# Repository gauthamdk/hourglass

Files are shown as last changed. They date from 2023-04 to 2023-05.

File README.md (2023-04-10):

# hourglass

### [Ideation + Laser Cut Experiment | April 6, 2023 ](https://github.com/gauthamdk/hourglass/tree/main/ideation)

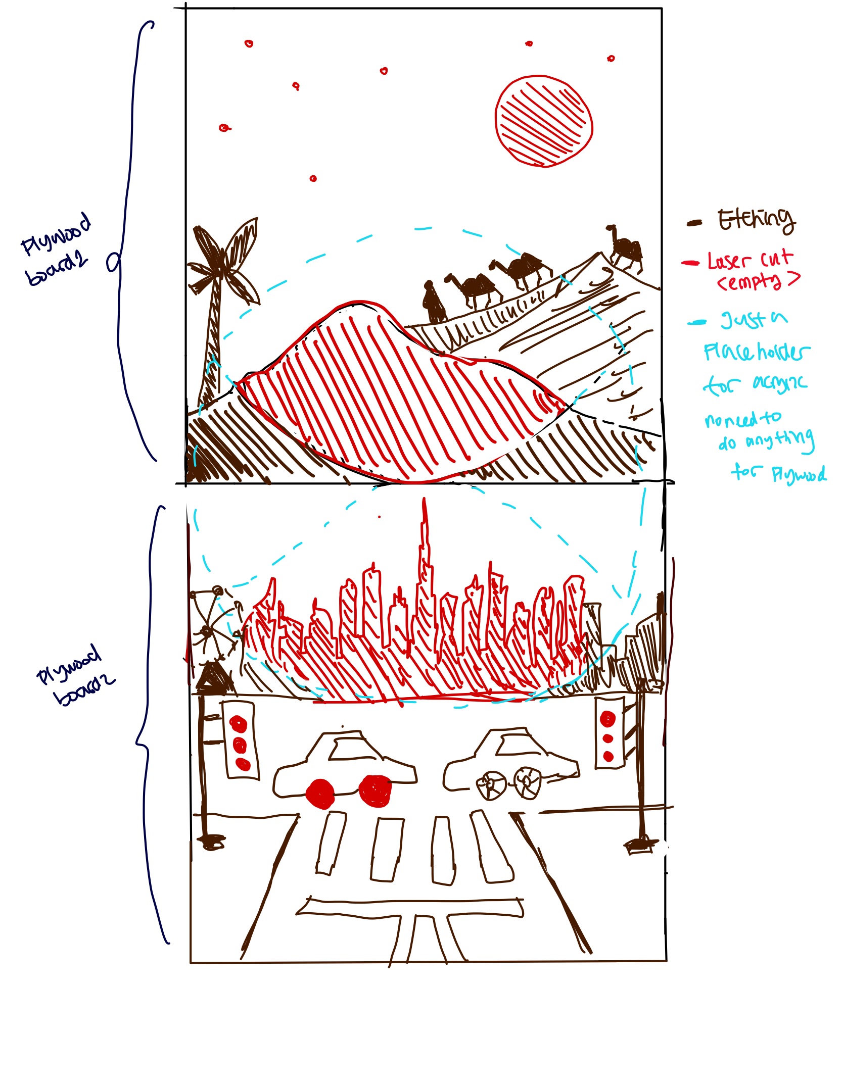
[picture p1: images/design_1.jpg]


# Core Idea
The core concept of our project is to illustrate the flow of time in the U.A.E. using the flow of sand. The project will occupy two boxes, 100cm long and 50cm wide, vertically oriented. A flat hourglass will be placed between the two boxes at the center of the piece, and will rotate at the beginning of every hour. The placement of the hourglass will be exactly at the center of the piece, 25cm below the top and 25cm above the bottom. Another layer of lasercutted acrylic will conceal the hour glass from viewers, only showing certain parts of the flowing sand. The contents of the acrylic board is detailed below. 

# Design Details
The flow of time will be portrayed through the artistic cutouts of the acrylic board, covering the entire span of the two wooden boxes. The design of the top half of the board will portary the U.A.E. of the past, and the bottom half will show the U.A.E. today. If the piece is split into four sections from top to bottom, the flow of sand will be shown in the 2/4 and 3/4 section, and the 1/4 and 4/4 sections will be decorational and supplemental. 

## The 1/4 Section
In this section, we will have cutouts of stars and the Sun on the acrylic board. White light will be placed behind the stars, and an orange/red light will be placed behind the Sun. When the 2/4 section (old U.A.E.) is full of sand, the Sun's light will be on full brightness, and the stars' lights will be the most dim. As sand flows from the 2/4 section to the 3/4 section (new U.A.E.), the Sun's light will progressively get dimmer and the stars' lights brighter. When 2/4 has no sand left, the stars will be on full brightness and the Sun will have no light. 

The goal of section 1/4 is to demonstrate old U.A.E. fading with time, with the Sun metaphorically setting as night time comes. 

## The 2/4 Section
This section will portray sand dunes, camels, and the inhabitants of the U.A.E. decades ago. In the fan shaped window where the sand from the hourglass is visible, the acrylic board will be fully hollow. For example, the sand dunes will be hollow, allowing the actual sand from the hourglass to providing the fillings of the cutouts. The sections of 2/4 that does not have the hourglass behind it will still continue the image of the sand dune, but will be laser etched instead of cut. These are the places that the camels and inhabitants will be placed. 

## The 3/4 Section
This section will portray the new U.A.E., mirroring section 2/4 in terms of its layout. The parts that have the hourglass behind it will be hollow, portraying iconic buildings of the U.A.E such as the grand mosque and the Burj Khalifa. The parts that do not have the hourglass behind will be etched instead, displaying Etihad and Emirates airplanes. 

## The 4/4 Section
This section will be complimentary to section 3/4, with cars and street lights etched and cut into the board. The body of the cars will likely be cut, and the wheels of the cars will be hollow, with actual mini-wheels protruding from the surface. The body of the street lights will be etched, with the actual light bulbs hollow. LED lights will be placed behind these light bulbs. As sand flows from section 2/4 to 3/4, the wheels of the cars will go from static to fully spinning, and the street lights will go from dim to full brightness.

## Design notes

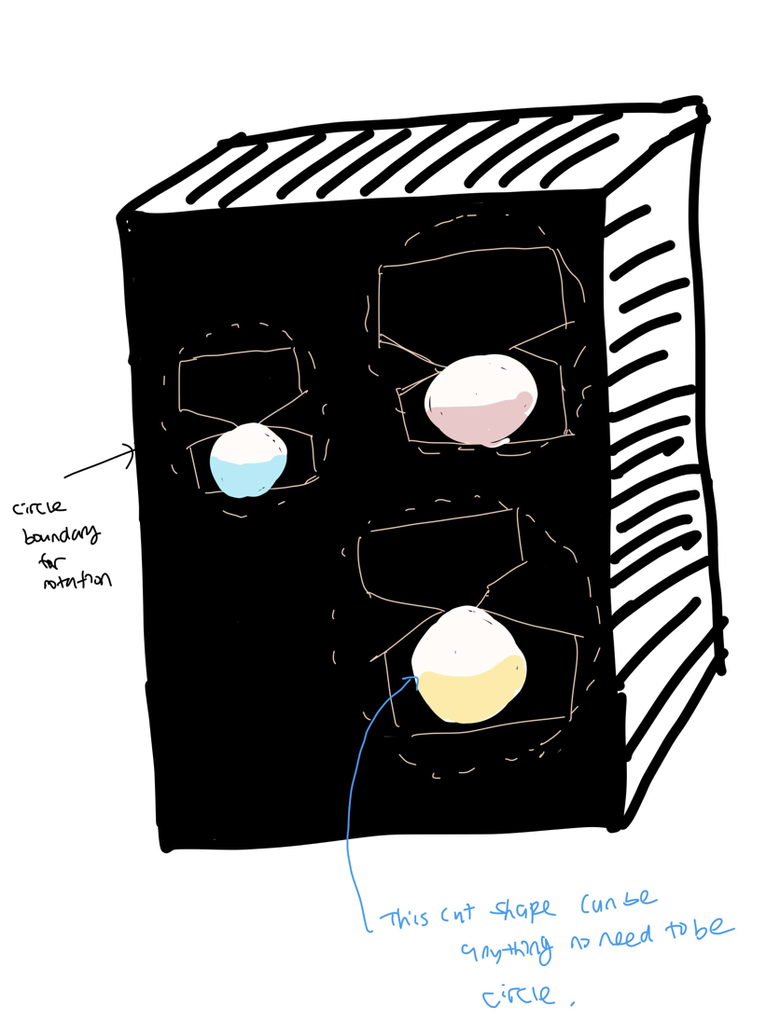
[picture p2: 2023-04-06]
images/rotation_mechanics.png

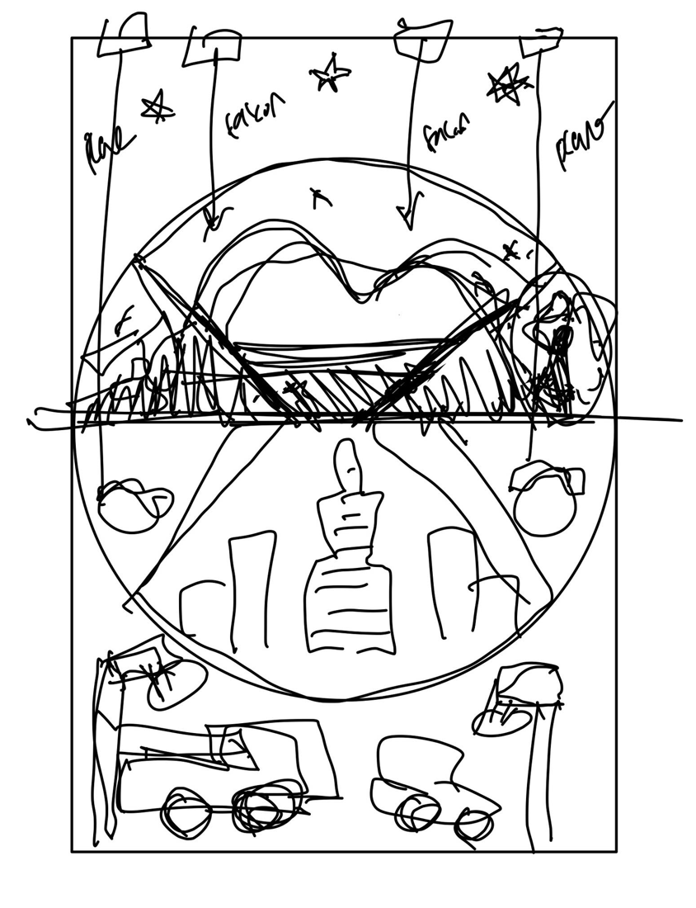
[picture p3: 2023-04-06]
images/oldtonew.1.png

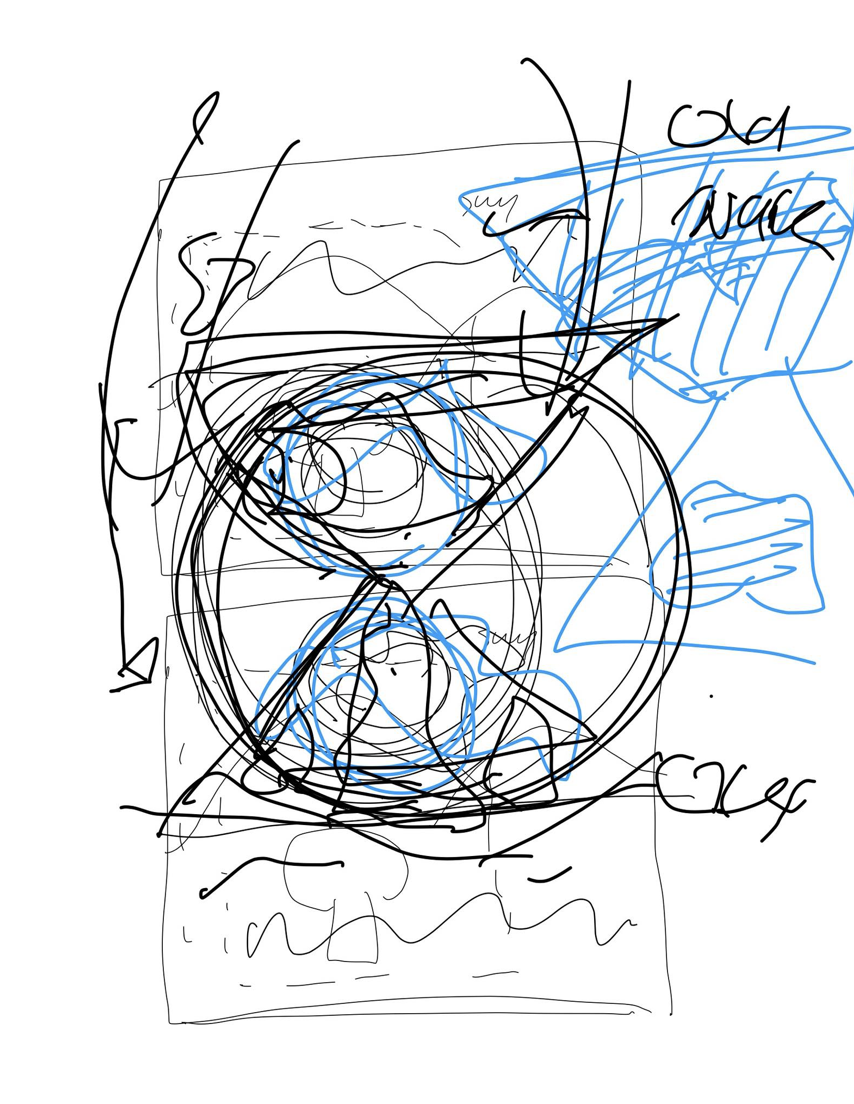
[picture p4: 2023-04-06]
images/rotation.png

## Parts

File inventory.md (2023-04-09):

# Items List

1. 50 x 50 cm acrylic board for hourglass (laser cut hourglass shape)
2. 50 x 50 cm (2 pieces) for sandwiching the hourglass plywood
3. 2 boxes from Professor Shiloh to form 2 storeys
4. 100 x 50 cm plywood for laser cutting shapes for dunes, stars and buildings and etching for cars, falcons, etc.
5. Servo motor to spin the hourglass
6. Fine sand to fill the hourglass. 
7. LED lights for stars

## Items if time permits

1. Servos to move falcon wings
2. DC motor to move car tires
3. 3D printing or laser cutting the falcons

# TODO

1. Prototype hourglass with cardboard
2. Draw hourglass shape on illustrator
3. Draw scene with cutout and etching on illustrator
4. Prototype the scene with cardboard
5. Adjust based on prototypes
6. Build final pieces with plywood and acrylic
7. Build platform to place servo 
8. Get sand for hourglass

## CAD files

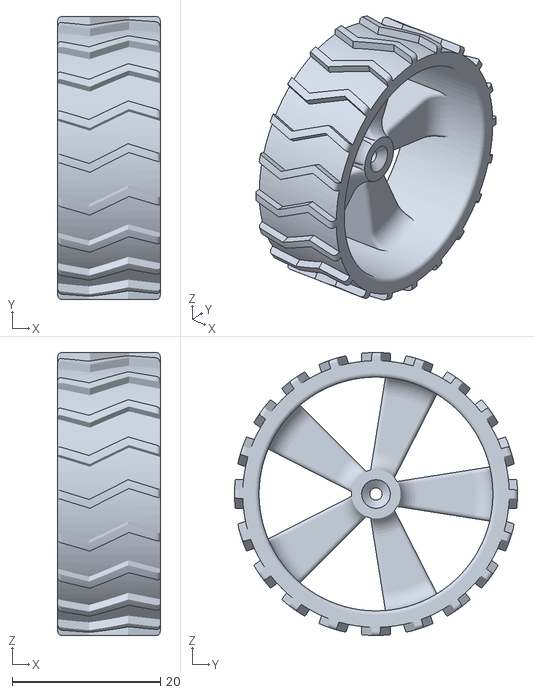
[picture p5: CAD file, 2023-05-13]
Wheel(1).stl
13.8 x 38.2 x 38.2

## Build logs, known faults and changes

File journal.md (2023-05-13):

# April 10th
In this class session, we divided our work into hourglass prototyping and illustrator designing. Nathan mainly worked on the hourglass prototype, and Gautham and Soojin were designing the acrylic cutouts. 

## Hourglass prototype
Due to a lack of acrylic material, we decided to use cardboard to simulate an acrylic hourglass. In the previous class, we had breifly lasercut a cardboard hourglass, and that was the hourglass we worked with in this prototype. The main difference between cardboard and acrylic for our project was that we had to address the holes on the side of the cardboards, which we simly taped up. Here is the cardboard hourglass:

<p align="center" width="100%">
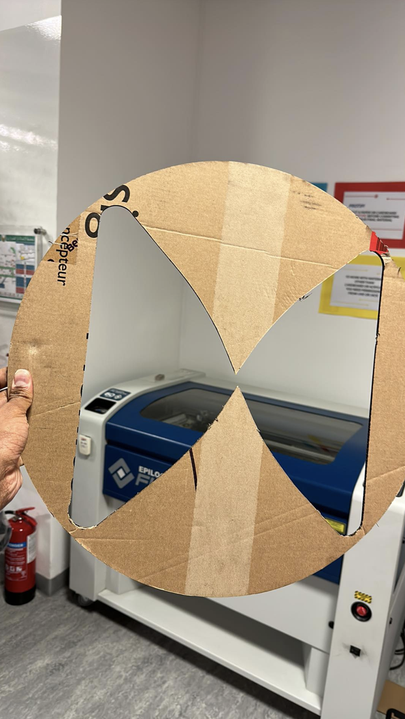
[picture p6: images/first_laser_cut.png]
    
</p>

Next, we glued the cardboard hourglass to a flat cardboard surface, and then started filling in the hourglass with sand. Since we want the sand from the hourglass to provide a solid filling for the plywood cutout in the front, the sand needed to perfectly fill in half of the hourglass. After some trial and error, the sand filling was completed, and we moved onto gluing a transparent acrylic board onto the sand-filled hourglass. This proved to be the hardest part of the prototype, as the acrylic board was heavy and hard to glue seamlessly onto the uneven cardboard surface. We tried glue guns, white glue, and acrylic glue, but none of the options worked. In the end, since the hourglass was only a prototype to test the flow rate, we decided to just use clamps to hold down all sides of the acrylic board. The prototype looked like this:

<p align="center" width="100%">
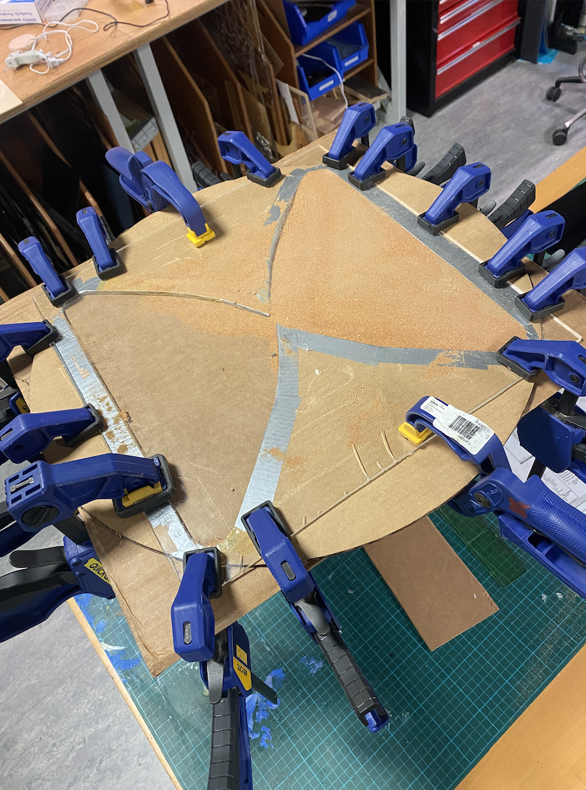
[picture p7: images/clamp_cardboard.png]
    
</p>

Even with using as many clamps as we did, the sand was still leaking from the sides, as well as going around the hourglass as it flowed down into the bottom. However, most of the sand flowed decently through the hole of the hourglass, and we were able to find out that a 5mm hole is much too big. The total flow time did not even last five seconds. Overall, this prototyping session was very helpful for us in getting a rough estimate of the hourglass dimensions. Here are some videos of the prototype: 

[Test 1](images/sand_cardboard_porrotype.MOV)
[Test 2](images/sand_cardboard_2.MOV)
[Test 3](images/sand_cardboard_3.MOV)

# April 12th
Gautham and Soojin finalized their illustrator work from April 10th, and plan to lasercut their design on April 13th. Here is the current design:
<p align="center" width="100%">
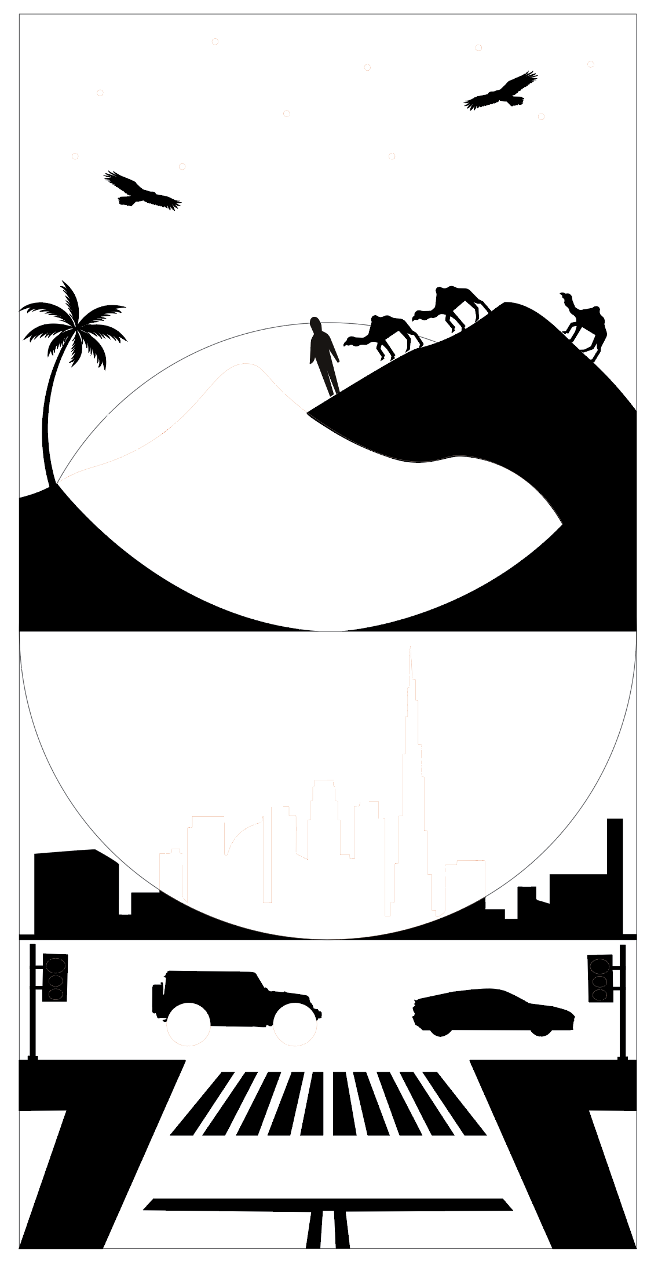
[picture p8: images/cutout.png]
    
</p>
The black circle in the middle is the area where the hourglass will rotate. The thick black strokes are all areas that will be laser etched into the plywood surface, and the think pink lines will be the places where the plywood is laser cut. There are three sections of these laser cuts, including the sand dune at the top, the U.A.E. skyline, and the wheels of the jeep underneath the skyline. 

# April 17th
During this class, we focused on prototyping and testing our laser cutting design.

## Prototyping
### Motor
Nathan and Soojin worked primarily on the prototyping process. Soojin focused on testing the hourglass, while Nathan worked on testing the motor. For the motor testing, our primary concern was the capability of the servo motor in handling the weight of the piece. We used a piece of plywood that was similar in weight to the final hourglass, bolted the servo motor onto the wood, and tested its turning ability. Despite Nathan eyeballing its centering on the wood, we found no concerns regarding the motor's capabilities for the final piece.

It's important to note that we originally designed a structure that would secure the motor to the hourglass. However, after realizing that the motor had its own securing mechanisms, we no longer believe that we need any additional mechanisms to secure the motor to the hourglass. Please see the photos and videos of the motor prototyping process below.
<p align="left" width="100%">
    
    
    
</p>
MOTOR PICS AND VIDS

### Hourglass
Soojin led the hourglass testing. For hourglass testing, our aim was to understand the behavior of sand moving from one side to the other on a thin, ribbon-shaped surface in our design. Based on the speed of the sand movement, our next step is to identify the size of the hole that connects the two sections.

For the prototype, we used acrylic as the cover, cardboard as the hourglass-shaped cutout, and another cardboard as the supporting board. The cardboards were sealed with duct tape to prevent sand from entering the corrugated space. We then clamped the three layers together to ensure enough pressure and a tight seal. Since the materials used were not consistent, such as three acrylic layers or three cardboard layers, it was difficult to "glue" them, which is why we used clamps for the experiment.

<p align="center" width="100%">

</p>

<b>Video of sand moving below:</b>
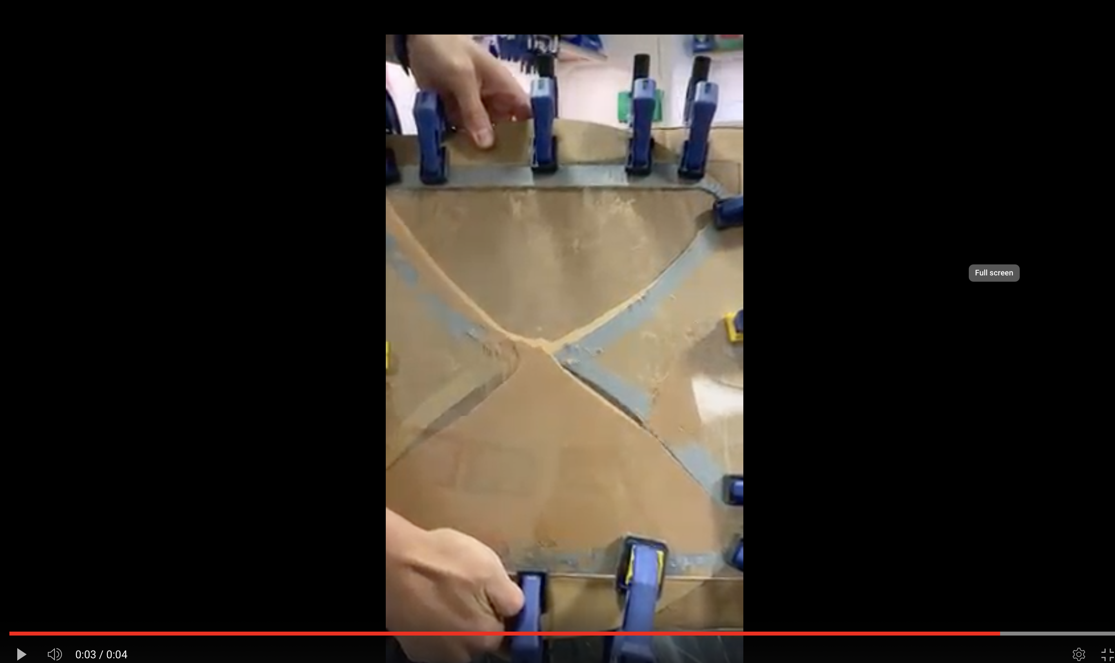
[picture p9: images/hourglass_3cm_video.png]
Image ALT text


As expected, the sand moved quickly through the hole, taking only 4 seconds to move from one side to the other. However, to achieve the desired speed of 15-20 minutes for sand to move from one place to another, we decided to try using 0.05cm for the next prototype.

[Things to consider]

- Color of sand (considering the plywood background, what color sand would be impactful?)
- Which material to use to glue acrylic to plywood
- Thickness of Acrylic
- Make hole size adjustable using nuts and bolts

## Laser Cutting
Gautham led the laser cut design testing process. The cardboard result looked great, but the laser cutting machine in the IM lab was not large enough for the full scale of our project. Therefore, we scaled down the design just to test it out. Here is how it turned out:
<p align="left" width="100%">
    
    
</p>
The initial result had some errors, such as the sand dune not being cut out and the skyline on the bottom being proportionally smaller than the sand dunes. To fix these issues, we decided to make the skyline bigger in our next design and change the skyline from Dubai to Abu Dhabi, where the building heights are more even. Additionally, we were not happy with the star design, so we changed them to actual star shapes in the second design. Please see the second design below.

# April 24th

<p align="center" width="100%">
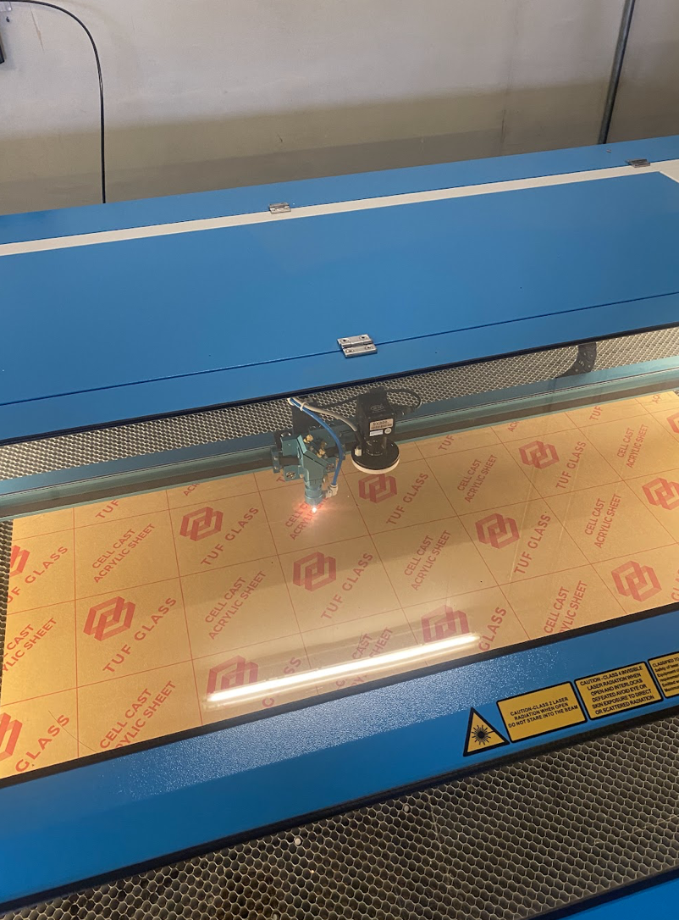
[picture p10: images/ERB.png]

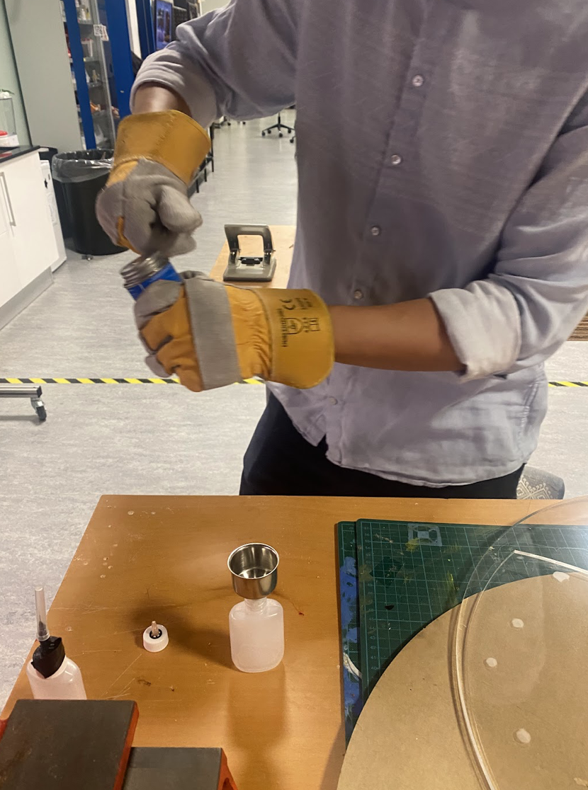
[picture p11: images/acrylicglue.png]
    
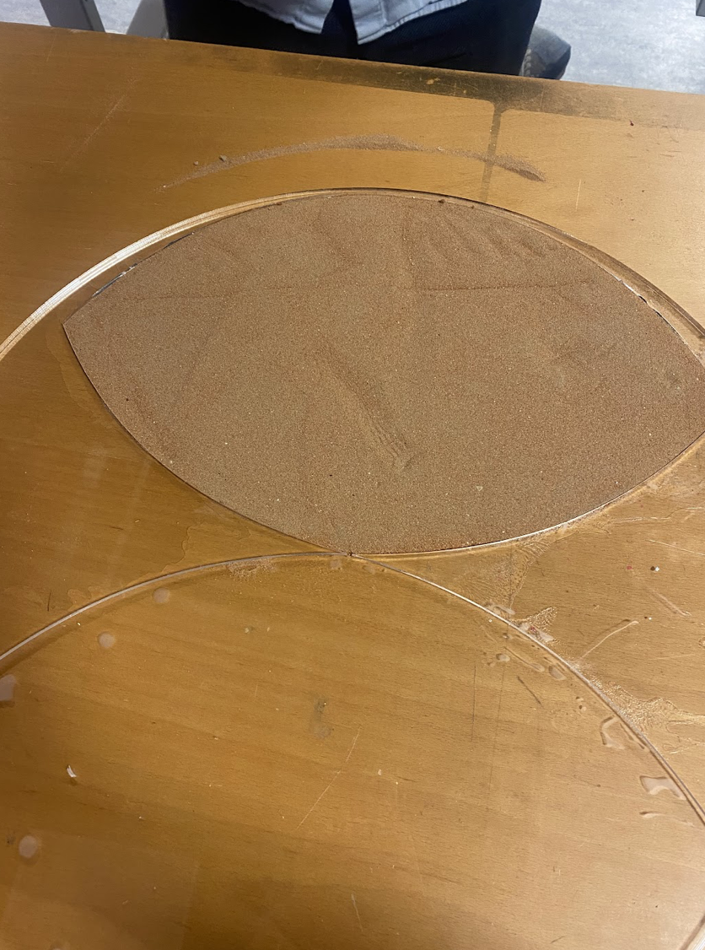
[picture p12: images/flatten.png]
    
</p>
In this class, we primrily tested out our hourglass design with actual transparent acrylic. We went to the machine lab and cut out the design with the large laser cutter, then used acrylic glue to merge the layers of the hourglass. The main issue in this step is that there are three layers of the hourglass, which makes the last layer very hard to glue. We have to trace the hourglass ledges with the glue, then blindly place the final layer on top. We did not succeed in gluing the last layer until the next day. Here is the end result:

<p align="center" width="100%">

</p>

There were a few isues. One, the last layer was not completely sealed to the rest due to the difficulty in gluing. For the final design, we will put more glue. There was also any issue of the sand getting blocked due to small rocks sealing the hourglass gap. We will sort through the batch of sand we use for the final design. Finally, the sand did not fully flow through, mainly becuase the bottom ledge of each half are curved. Small amounts of sand were tracked in the two pockets and would not flow freely. To remedy this issue, we have made the curved ledges straight. 

# April 28th
<p align="center" width="100%">
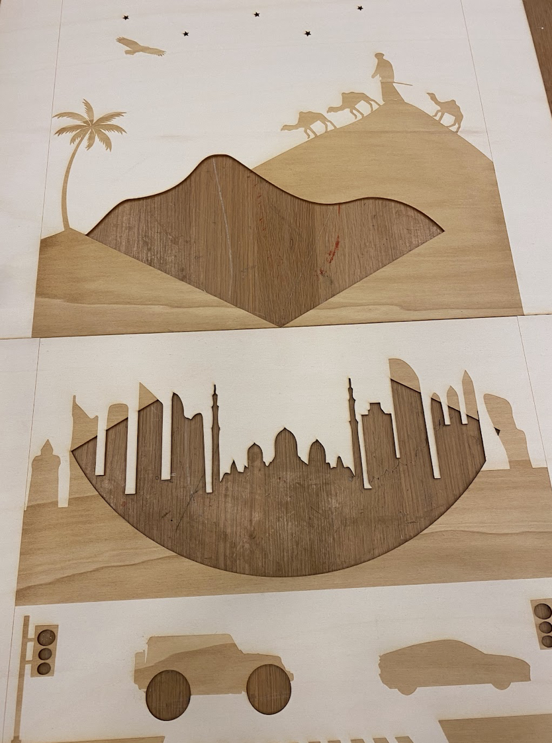
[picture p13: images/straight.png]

</p>

After encountering some trial and error with the first acrylic cut, we made a second cut. This time, we made the hole between the top and bottom of the hourglass much smaller (0.3cm) and straightened the curve to ensure that the sand flows smoothly without getting stuck. We also redesigned and laser cut the plywood board so that its line is aligned with the new straight line of the hourglass acrylic board. The acrylic board is sandwiched as such: 0.4mm thin transparent acrylic board (circle shape) 0.4mm transparent acrylic board cut to hour glass shape, and 0.8mm thick black acrylic board.

<p align="center" width="100%">
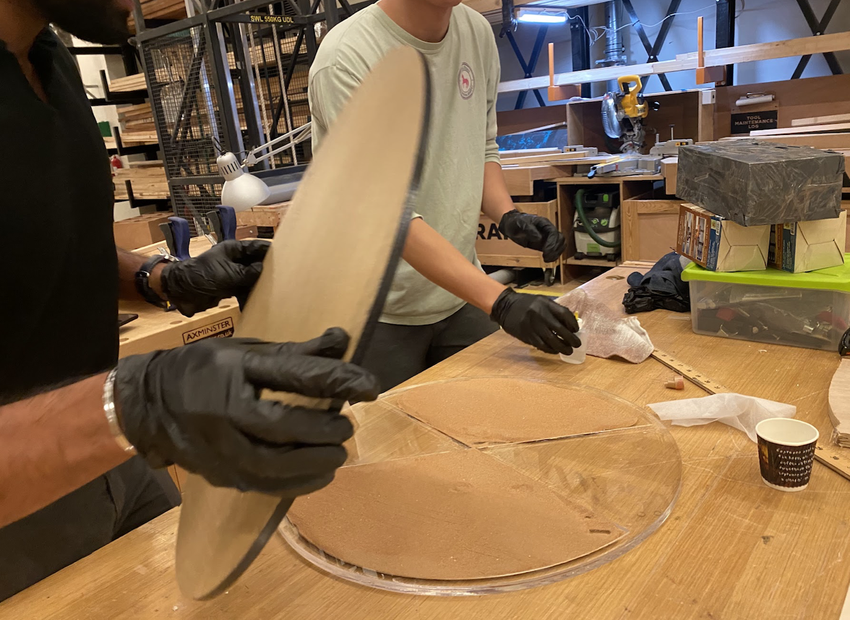
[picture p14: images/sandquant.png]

</p>

Finding the exact amount of sand to add before sealing the hourglass was difficult. Therefore, we added more than half of the sand, and then drilled a hole in the center to pour out any excess sand once the bottom is filled.

# May 1st 
We found an online model for the 3D [file](./Wheel(1).stl) of car wheels that I thought was suitable for the project. I modified the scale of the wheel to fit the cutout and sent the files to the library to print. We received it the following day and spray painted it silver to match the aesthetic.

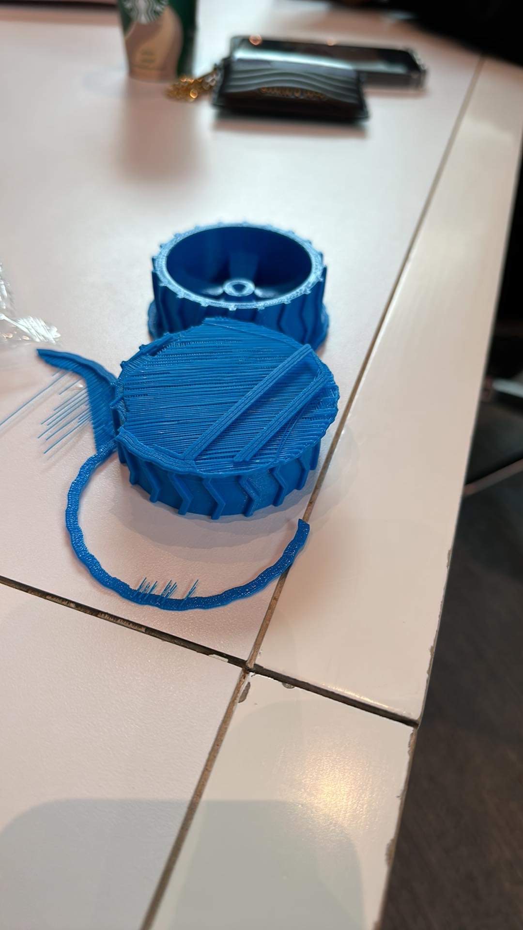
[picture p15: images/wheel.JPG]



# May 5th
We secured the frame structurally today, including implementing a floor, two supporting boards on the side, and a board in between. The "H" structure adequately secures the integrity of the frame.

We spray painted the car wheel and attached to the main plywood board. 

# May 7th 
We did some soldering for the connections on the design frame, including the soldering for the star light connections. We also drilled some holes into the board that will ultimately host all the wires and arduinos in order to provide space for the wires. 

For the light connections, I etched the stars on a smaller piece of plywood and soldered the Neopixel LEDs onto the plywood and secured them with them. We then attached this to the back of the cutout with some screws to align it properly.

# May 8th
We finalized assembling the project, including replacing all of the jumper wire connections with solder and attached the design frame to the project frame. The mechanisms did not work initially after we soldered everything, including the stars, traffic lights, and hourglass. However, after some testing with the multimeter, the professor helped us trouble shoot the issue and tidy up the connections. 

Now it was left with the code. The code was each individual component like the stars and traffic lights, the wheels and the hourglass rotation was simply to code independently. But togther I need to use millis() to count the number of minutes that passed to toggle between the different modes. 

Initially, the hourglass would rotate till sand is flowing down. As the sand flows for 3 minutes and the bottom starts getting filled, I dim the stars at the top and the traffic lights turn from red to green and the car wheels rotate. At 6 minutes, the hourglass does another rotation, the traffic lights turn red and the car wheels stop. The stars also become bright again. 

I also added the trigger that would come from the clock so that the mechanism only starts when the trigger is received and when it is finished after 6 minutes we send a signal back but this was later discarded. 
# May 10th
<p align="center" width="100%">
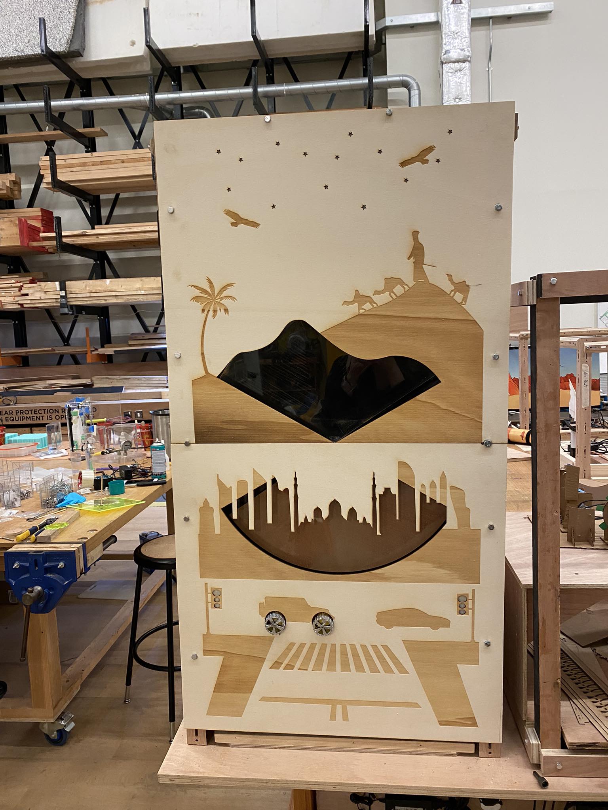
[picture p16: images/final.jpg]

</p>

[Reflection & Learnings]
During the final construction period, we found ourselves continuously unbolted the plywood to fix mechanisms behind and between the hourglass structure and the plywood. We learned that creating an accessible design that allows easy access to fix compartments is really important - it would have saved us a lot of time. For example, when the neopixel lights were slightly off-grid and one motor stopped working, we had to undo the plywood, which was time-consuming.

<p align="center" width="100%">
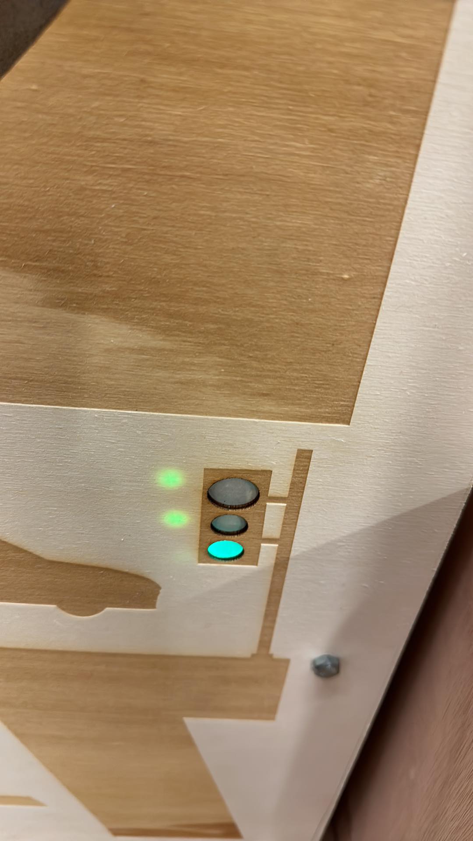
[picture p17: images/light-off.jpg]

</p>

Learning how to solder properly and prevent short circuits that can cause electrical burnout was a valuable lesson from this project. One thing we can improve upon is to pre-plan and color-coordinate wires, such as using black for ground and red for power supply, for instance.

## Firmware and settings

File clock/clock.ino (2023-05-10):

/*
 * Created by ArduinoGetStarted.com
 *
 * This example code is in the public domain
 *
 * Tutorial page: https://arduinogetstarted.com/tutorials/arduino-neopixel-led-strip
 */

#include <Adafruit_NeoPixel.h>
#include <Servo.h>
#ifdef __AVR__
#include <avr/power.h>  // Required for 16 MHz Adafruit Trinket
#endif

#define PIN_NEO_PIXEL 10  // Arduino pin that connects to NeoPixel
#define NUM_PIXELS 20
#define NUM_TRAFFIC 6
#define NUM_STARS 14
#define STARS_START 3
#define SERVO_PIN 9

const int TRIGGER = 2;
const int DONE = 12;

const int IN1 = 7;
const int IN2 = 6;
const int IN3 = 5;
const int IN4 = 4;

int servoStart = 0;
int carWheelsOn = 0;
int end = 0;

unsigned long timer;
unsigned long end_timer;

int TRAFFIC_LIGHTS[NUM_TRAFFIC] = { 0, 1, 2, 17, 18, 19 };

int pos = 0;
int startClock = 0;
int turned = 0;
int ten_degree_turned = 0;
int reset_ten_degree = 0;
unsigned long ten_degree;

int thirty_degree_turned = 0;
int reset_thirty_degree = 0;
unsigned long thirty_degree;

Adafruit_NeoPixel NeoPixel(NUM_PIXELS, PIN_NEO_PIXEL, NEO_GRB + NEO_KHZ800);
Servo myservo;

void setup() {

  // START and END SIGNAL
  pinMode(TRIGGER, INPUT);
  pinMode(DONE, OUTPUT);

  // CAR WHEELS
  myservo.attach(SERVO_PIN);  // attaches the servo on pin 9 to the servo object
  pinMode(IN1, OUTPUT);
  pinMode(IN2, OUTPUT);
  pinMode(IN3, OUTPUT);
  pinMode(IN4, OUTPUT);

  NeoPixel.begin();  // INITIALIZE NeoPixel strip object (REQUIRED)
  randomSeed(analogRead(0));
  timer = millis();
  ten_degree = millis();
  thirty_degree = millis();
  Serial.begin(9600);
  stars();
  myservo.write(0);
  trafficLightsOff();
}

void loop() {

  unsigned long current = millis();
  if(end && current - end_timer < 200){
      digitalWrite(DONE, 1);
  }else{
    end = 0;
    digitalWrite(DONE, 0);
  }

  int inputVal = digitalRead(TRIGGER);
  Serial.println(inputVal);
  if (inputVal == 1){
    Serial.println("Trigger");

    if (!startClock){
      if(pos == 0){
          myservo.write(120);
          pos = 120;
        }
        else{
          myservo.write(0);
          pos = 0;
        }
    }

    startClock = 1;
  }

  if (startClock){
    unsigned long currentTime = millis();
    if (currentTime - timer > 300000) {
      timer = currentTime;
      ten_degree = currentTime;
      thirty_degree = currentTime;
      carWheelsOn = 0;

      Serial.println("turning 180");

      // turn hourglass
      if (pos == 120) {
        myservo.write(0);
        pos = 0;
        // send signal to end
      } else {
        myservo.write(120);
        // turned = 1;
        pos = 120;
      }

      startClock = 0;
      end = 1;
      end_timer = millis();

      stars();
      trafficLightsOff();
    }

    // Serial.println(carWheelsOn);
    if (carWheelsOn){
      carWheels();
    }else{
      carWheelsOff();
    }


    // turn hourglass 10 degress left and right at 3 mins and dim lights
    currentTime = millis();
    if (currentTime - ten_degree > 180000) {
      // Serial.println("turning 10");
      ten_degree = currentTime;
      ten_degree_turned = 1;

      dimStars();
      trafficLights();
      carWheelsOn = 1;

      pos += 20;
      myservo.write(pos);
    }

    currentTime = millis();
    if (ten_degree_turned && (currentTime - ten_degree > 10000)) {
      // Serial.println("turning back 10");
      ten_degree = currentTime;
      ten_degree_turned = 0;
      reset_ten_degree = 1;
      pos -= 40;
      myservo.write(pos);
    }

    currentTime = millis();
    if (reset_ten_degree && (currentTime - ten_degree > 10000)) {
      // Serial.println("resting 10");
      reset_ten_degree = 0;
      pos += 20;
      myservo.write(pos);
    }

  }
  
}

/////// CAR WHEELS//////////
void carWheels(){
  digitalWrite(IN1, HIGH);
  digitalWrite(IN2, LOW);
  digitalWrite(IN3, HIGH);
  digitalWrite(IN4, LOW);
}

void carWheelsOff(){
  digitalWrite(IN1, LOW);
  digitalWrite(IN2, LOW);
  digitalWrite(IN3, LOW);
  digitalWrite(IN4, LOW);
}

void stars(){
   // Stars
      for (int pixel = STARS_START; pixel < NUM_STARS + STARS_START; pixel++) { // for each pixel
          NeoPixel.setPixelColor(pixel, NeoPixel.Color(255, 255, 255)); // it only takes effect if pixels.show() is called
          NeoPixel.show();
      }
}

void dimStars(){
   // Stars
      for (int pixel = STARS_START; pixel < NUM_STARS + STARS_START; pixel++) { // for each pixel
          NeoPixel.setPixelColor(pixel, NeoPixel.Color(25, 25, 25)); // it only takes effect if pixels.show() is called
          NeoPixel.show();
      }
}

void trafficLights(){
   // Traffic lights
    for (int pixel = 0; pixel < NUM_TRAFFIC; pixel++) { // for each pixel
      NeoPixel.setPixelColor(TRAFFIC_LIGHTS[pixel], NeoPixel.Color(0, 255, 0)); // it only takes effect if pixels.show() is called
    }
    NeoPixel.show();
  }

void trafficLightsOff(){
   // Traffic lights
    for (int pixel = 0; pixel < NUM_TRAFFIC; pixel++) { // for each pixel
      NeoPixel.setPixelColor(TRAFFIC_LIGHTS[pixel], NeoPixel.Color(255, 0, 0)); // it only takes effect if pixels.show() is called
    }
    NeoPixel.show();
  }
